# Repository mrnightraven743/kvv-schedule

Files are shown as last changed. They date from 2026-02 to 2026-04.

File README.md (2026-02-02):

# ESP32 Train Schedule Monitor (Deutsche Bahn Style)

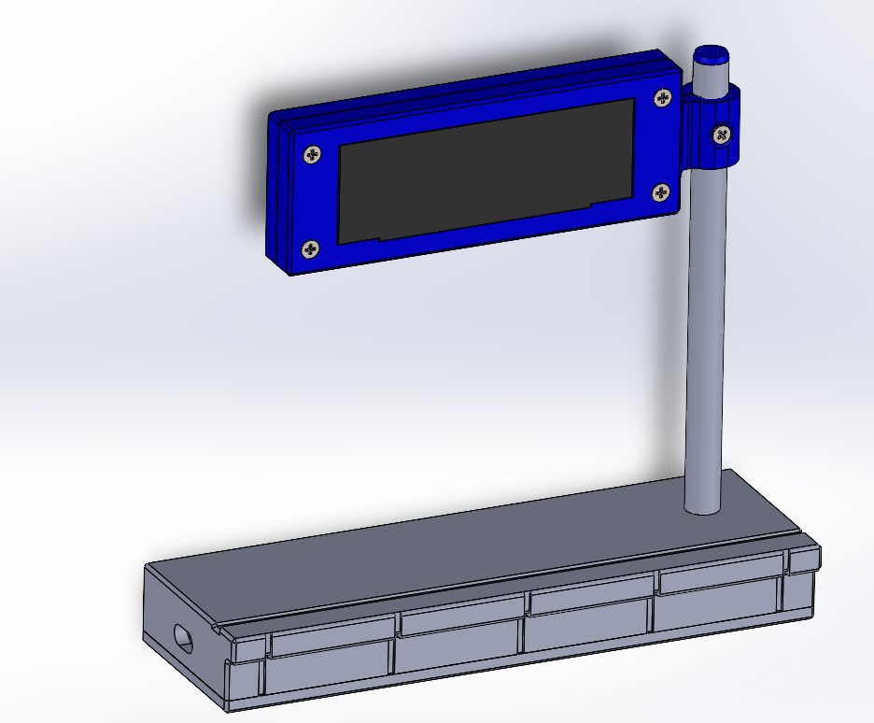
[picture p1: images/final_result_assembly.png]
Final Result


A desktop train schedule monitor stylized after the modern "DSA" (Dynamischer Schriftanzeiger) displays found on German railway platforms. It displays real-time departures for KVV (Karlsruher Verkehrsverbund) or Deutsche Bahn stations using an ESP32 and a high-resolution OLED display.

## ✨ Features

* **Hybrid Mode:** Fetches real-time data (API) when online. Falls back to a stored offline schedule if WiFi or the API is down.
* **Resilient Connectivity:** Auto-reconnects to WiFi. If the connection drops during the night, it updates as soon as the internet returns.
* **Automated Updates:**
    * **Backend:** GitHub Actions fetches the next 24h schedule every night (02:00 AM).
    * **Firmware:** The ESP32 downloads the new data file automatically at 03:00 AM (or upon reconnection).
* **Authentic Design:** Custom 3D-printed housing with an aluminum stand, modeled in SolidWorks.

## 📂 Repository Structure

* `firmware/`: MicroPython code for the ESP32 (Display driver, WiFi logic, Updater).
* `backend/`: Python script used by GitHub Actions to fetch data from KVV/EFA.
* `3d_models/`:
    * `stl/`: Ready-to-print files.
    * `step/`: CAD files for modification.
* `offline_data.py`: The daily generated schedule (updated automatically by the bot).

## 🛠 Hardware Required

1.  **MCU:** ESP32 DevKit V1 (30 pin).
2.  **Display:** 3.12" OLED SSD1322 (256x64 pixels, SPI interface).
3.  **Housing:** 3D printed parts (PLA/PETG) + Aluminum tube (10mm diameter).
4.  **Power:** USB Cable + 5V Adapter.

### Wiring (SPI)

| Display Pin | ESP32 Pin | Note |
| :--- | :--- | :--- |
| **VCC** | 3.3V | |
| **GND** | GND | |
| **SCK** (CLK) | GPIO 18 | |
| **MOSI** (DIN) | GPIO 23 | |
| **CS** | GPIO 5 | |
| **DC** | GPIO 17 | |
| **RST** | GPIO 16 | |

## 🚀 Installation Guide

### 1. GitHub Setup (Backend)
To enable automatic schedule updates, you need your own copy of this repository.

1.  **Fork** this repository.
2.  Go to `backend/kvv_processor.py` and change the `STOP_ID` to your desired station ID.
3.  Go to the **Actions** tab in your repository and enable workflows.
4.  (Optional) Run the "Update Schedule" workflow manually once to generate the first data file.

### 2. ESP32 Setup (Firmware)
1.  Flash your ESP32 with the latest **MicroPython** firmware.
2.  Open `firmware/main.py` and configure:
    * `WIFI_SSID` / `WIFI_PASS`: Your WiFi credentials.
    * `STOP_ID`: Your station ID (for real-time requests).
    * `LAT` / `LON`: Your coordinates (for local weather data).
3.  Open `firmware/schedule_updater.py` and update `GITHUB_RAW_URL` to point to **your** forked repository (`raw.githubusercontent.com/...`).
4.  Upload all files from the `firmware/` folder to the root directory of the ESP32.

## 🖨️ 3D Printing & Assembly

The design is modular and fully serviceable, using M3 bolts and nuts.

### Bill of Materials (BOM)
* **Bolts:**
    * M3 x 20mm (Required for the Base).
    * M3 x 25mm (Recommended for the Display Case, 20mm can also work, required for the Base at least 1).
    * Small screws (e.g., M2) for mounting the ESP32 (or use Superglue).
* **Nuts:** Standard M3 nuts.
* **Tube:** Aluminum tube, 10mm outer diameter.

### Printing Tips
* **Material:** PLA or PETG.
* **Adhesion:** The **Base** part is long and prone to warping. It is highly recommended to use **glue stick** or adhesive spray on the print bed to ensure it stays flat.
* **Nozzle:** Designed for a standard 0.4mm nozzle.

### Assembly Notes
1.  **The Screen Clips:**
    The mounting holes on the SSD1322 PCB are extremely close to the edge. Printing holes for them directly would result in fragile 1-layer walls. Instead, the screen is held in place by **special printed clips (clamps)** that are secured by the main case bolts. Do not try to put screws directly through the PCB holes.
2.  **The Tube (Drilling):**
    * **Display:** Assemble the front and back of the display case *first*. Then insert the tube and drill through the plastic and aluminum together. This ensures perfect alignment and prevents the drill from wobbling.
    * **Base:** Insert the tube into the base first, then drill the fixing hole.
3.  **The Tube (Fit):**
    The 10mm tube is designed for a **tight press-fit** into the Base. You may need to lightly hammer it in. This design feature prevents the tube from rotating even before the locking bolt is inserted.
4.  **ESP32 Mounting:**
    The ESP32 can be secured in the base using small screws (if your board has holes) or simply glued in place with a drop of superglue.

## 💡 Notes

**Keep-Alive Mechanism:**
GitHub disables Actions after 60 days of inactivity. To prevent this, I use a simple cron script on a local Raspberry Pi that pushes a small update to `keep_alive_log.txt` once a month. This ensures the daily schedule updates continue indefinitely without manual intervention.

## 📜 License
This project is open-source. Feel free to modify and build your own!

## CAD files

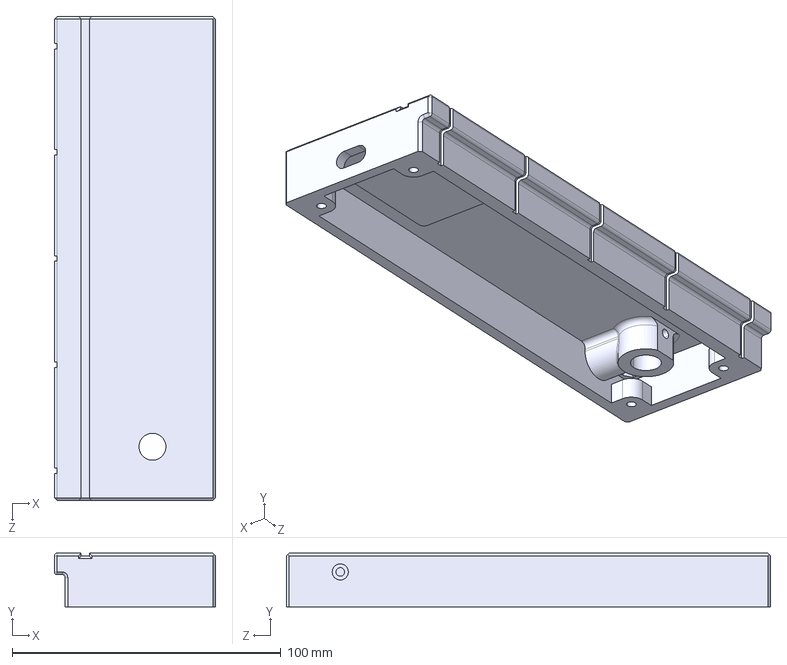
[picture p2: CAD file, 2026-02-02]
3d_models/step/base.STEP
60.0 x 20.0 x 180.0 mm

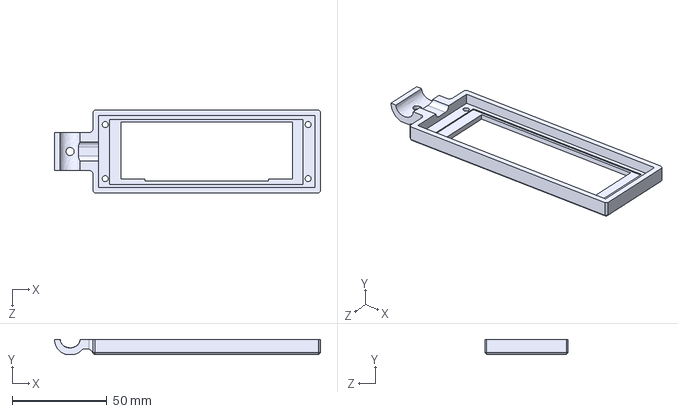
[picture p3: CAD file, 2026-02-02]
3d_models/step/display_housing_body.STEP
140.3 x 8.00 x 44.0 mm

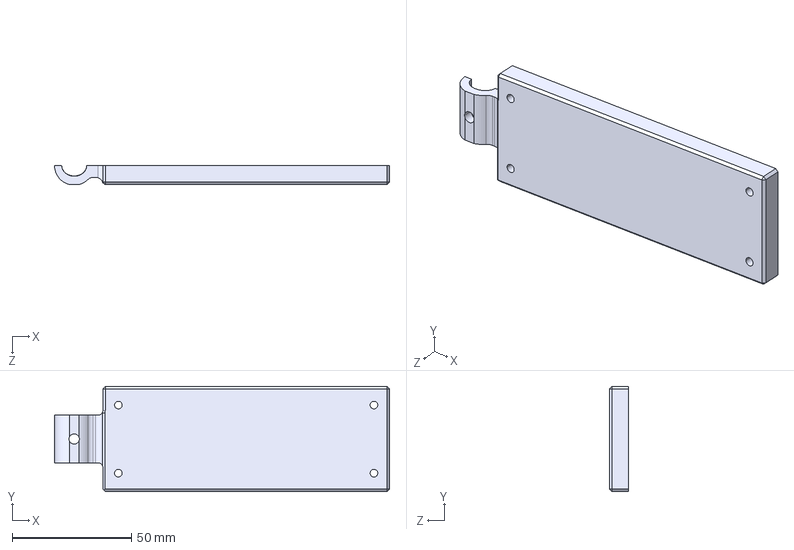
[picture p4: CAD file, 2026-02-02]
3d_models/step/display_housing_case.STEP
140.3 x 44.0 x 8.00 mm

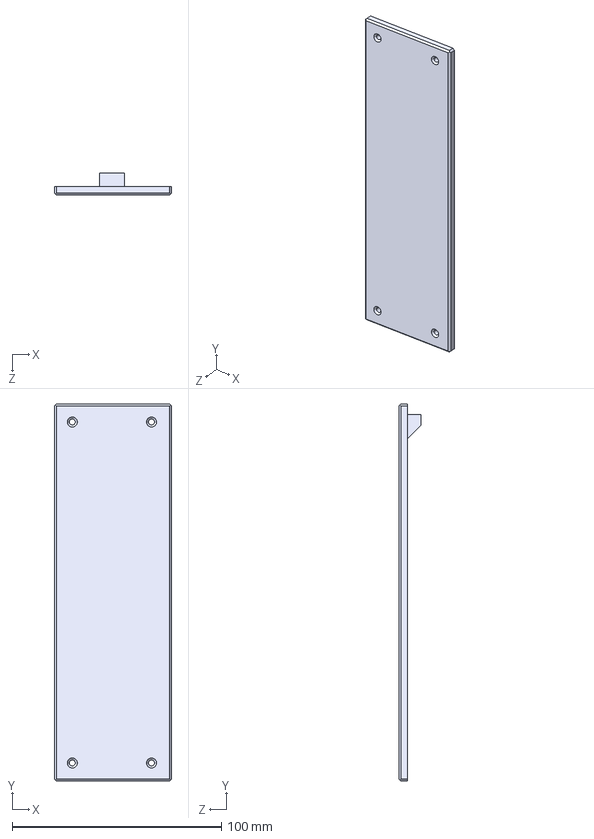
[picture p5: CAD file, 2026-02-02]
3d_models/step/base_lid.STEP
56.0 x 180.0 x 10.6 mm

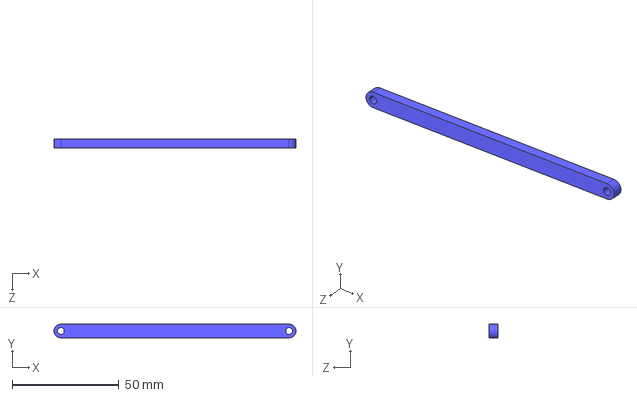
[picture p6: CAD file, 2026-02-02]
3d_models/step/display_holder.STEP
113.4 x 6.40 x 4.00 mm

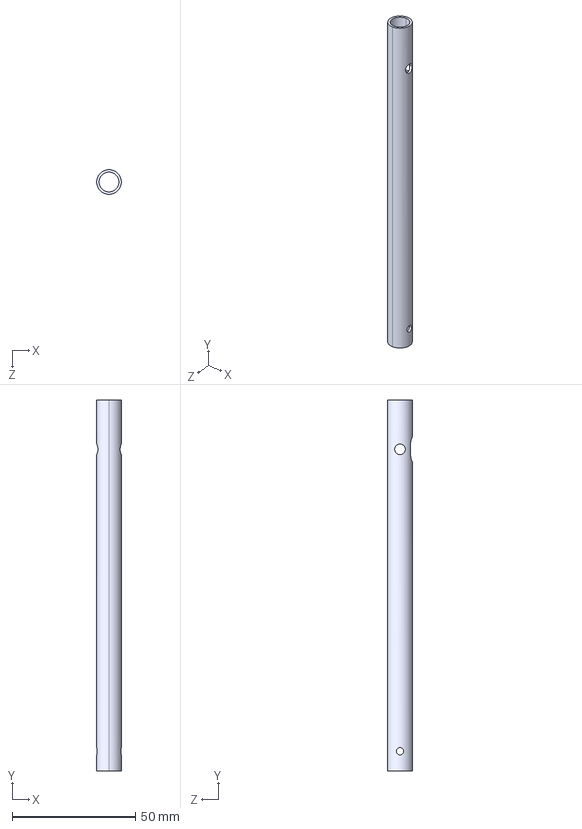
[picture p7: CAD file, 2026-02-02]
3d_models/step/tube_aluminium.STEP
10.0 x 150.4 x 10.0 mm

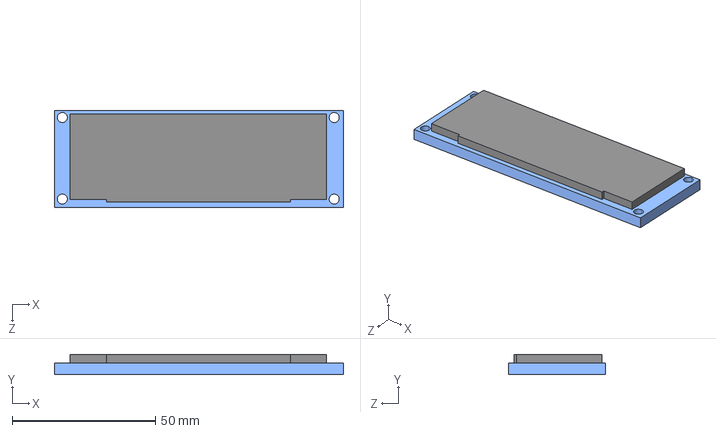
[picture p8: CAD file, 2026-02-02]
3d_models/step/monitor.STEP
101.0 x 7.00 x 34.0 mm

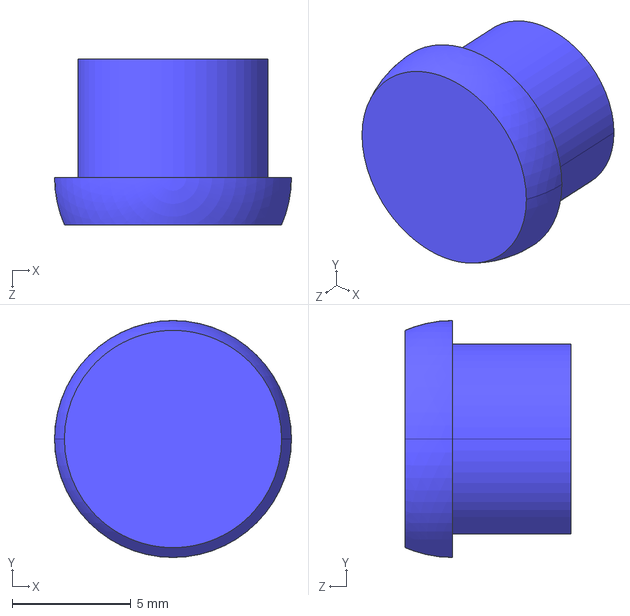
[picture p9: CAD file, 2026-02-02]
3d_models/step/pipe_top.STEP
10.00 x 10.0 x 7.00 mm

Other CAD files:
3d_models/stl/base.STL
3d_models/stl/base_lid.STL
3d_models/stl/display_holder.STL
3d_models/stl/display_housing_body.STL
3d_models/stl/display_housing_case.STL
3d_models/stl/pipe_top.STL

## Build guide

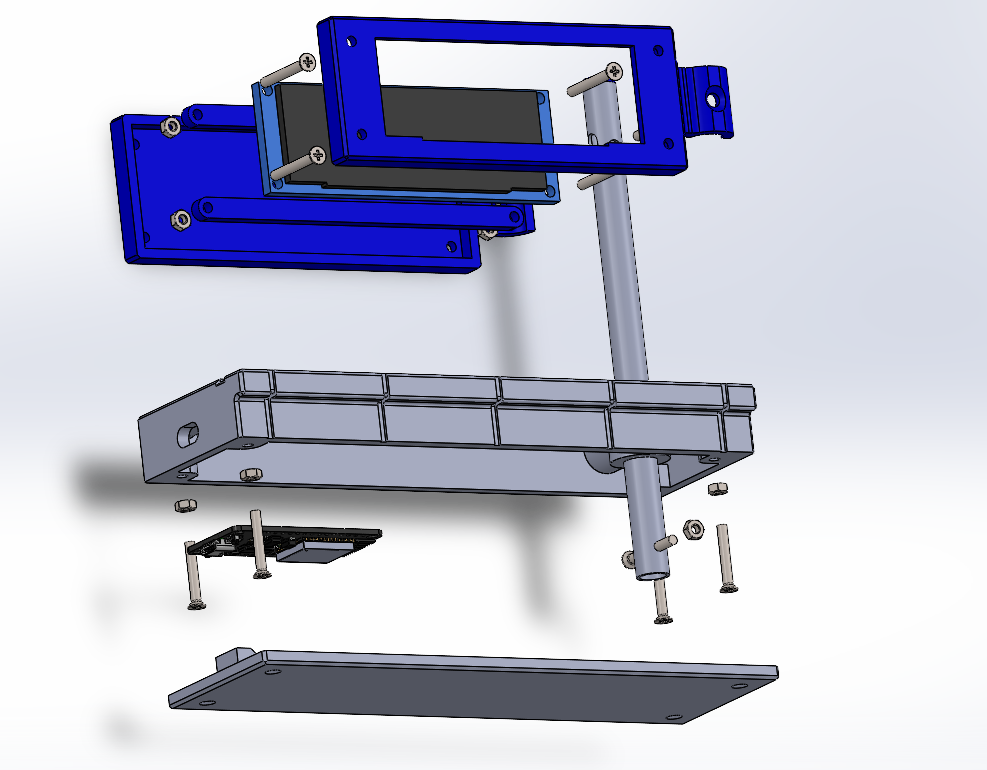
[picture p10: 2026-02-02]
images/final_result_assembly_exploded_view.png

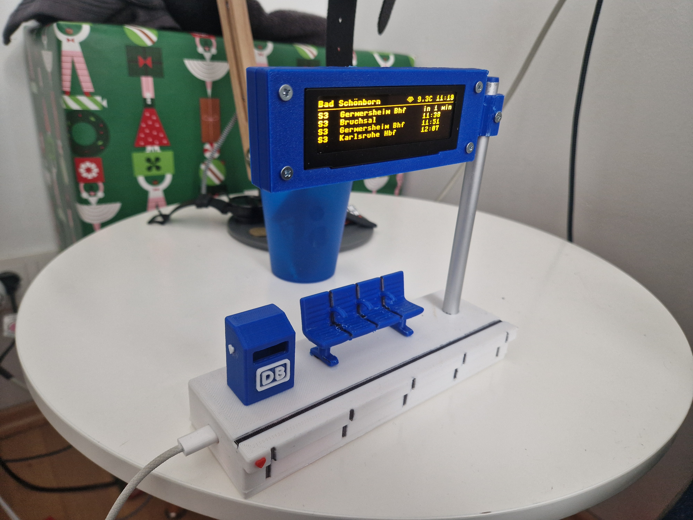
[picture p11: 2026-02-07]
images/3d_printed.jpg

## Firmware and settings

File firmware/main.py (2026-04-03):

import network
import time
import urequests
import json
import gc
import ntptime
import machine
import os
from machine import Pin, SPI, RTC
import ssd1322
import schedule_updater

# --- CONFIGURATION ---
WIFI_NETWORKS = [
    ("XXXX", "XXXX"),
    ("XXXX", "XXXX"),
    ("XXXX", "XXXX")
]

STOP_ID = "7001862" 
KVV_URL = f"http://www.kvv.de/tunnelEfaDirect.php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{STOP_ID}"
LAT = "49.2208"
LON = "8.6469"
WEATHER_URL = f"http://api.open-meteo.com/v1/forecast?latitude={LAT}&longitude={LON}&current_weather=true"

wifi_next_idx = 0

# --- DISPLAY CONFIGURATION ---
SPI_PORT = 2
SCK_PIN = 18
MOSI_PIN = 23
CS_PIN = 5
DC_PIN = 17
RST_PIN = 16

# Display reset sequence
rst = Pin(RST_PIN, Pin.OUT)
rst.value(1)
time.sleep(0.1)
rst.value(0)
time.sleep(0.2)
rst.value(1)
time.sleep(0.5)

spi = SPI(SPI_PORT, baudrate=10000000, sck=Pin(SCK_PIN), mosi=Pin(MOSI_PIN))
display = ssd1322.SSD1322(256, 64, spi, Pin(RST_PIN), Pin(CS_PIN), Pin(DC_PIN))

# WiFi initialization
wlan = network.WLAN(network.STA_IF)
try:
    wlan.active(True)
    wlan.config(pm=0xa11140)
except:
    pass

rtc = RTC()
last_weather = "" 
update_done_today = False 

# Import offline schedule data safely
try:
    import offline_data
except ImportError:
    offline_data = None 

# Text replacement dictionary to fit names on screen
REPLACEMENTS = {
    "Bahnhof": "Bhf", 
    "Straße": "Str.", 
    "Platz": "Pl.", 
    "Kaiserslautern, Hauptbahnhof": "Kaiserslautern", 
    "Kaiserslautern, Hbf": "Kaiserslautern", 
    "Kaiserslautern Hbf": "Kaiserslautern", 
    "Homburg (Saar) Hbf": "Homburg Hbf", 
    "Homburg (Saar)": "Homburg",
    "Hauptbahnhof": "Hbf",
    ", ": " ",
    
    "Вікторія": "Sonechko",
    "Наталя": "Mutter"
}

# Bitmap for WiFi icon
WIFI_BITMAP = ["   XXXXXXX   ", "  X       X  ", " X  XXXXX  X ", "X  X     X  X", "  X  XXX  X  ", "    X   X    ", "      X      "]

def shorten_text(text):
    """Abbreviates station names using the REPLACEMENTS dictionary."""
    for full, short in REPLACEMENTS.items():
        text = text.replace(full, short)
    
    if len(text) > 19:
        text = text[:19] + "."
    return text

def draw_umlaut_o(x, y):
    """Draws custom umlaut dots over 'o'."""
    display.pixel(x + 2, y - 1, 15)
    display.pixel(x + 5, y - 1, 15)
    
def draw_umlaut_a(x, y):
    """Draws custom umlaut dots over 'a'."""
    display.pixel(x + 2, y - 1, 15)
    display.pixel(x + 5, y - 1, 15)

def draw_wifi_icon(x, y, connected):
    """Draws WiFi icon if connected, or a cross if disconnected."""
    if connected:
        for r, s in enumerate(WIFI_BITMAP):
            for c, char in enumerate(s):
                if char == 'X':
                    display.pixel(x + c, y + r, 15)
    else:
        # Static cross
        display.line(x, y, x+9, y+8, 15)
        display.line(x+9, y, x, y+8, 15)

def wifi_reset():
    """Hardware reset for the WiFi interface."""
    print("WiFi Interface Reset...")
    try:
        wlan.active(False)
        time.sleep(0.5)
        wlan.active(True)
        time.sleep(0.5)
    except:
        pass

def safe_connect(silent=False):
    """
    Connects to WiFi. 
    silent=False: Blocking loop with display updates (used on startup).
    silent=True: Background mode, tries one network and exits.
    """
    global wifi_next_idx
    
    # Return if already connected
    if wlan.isconnected():
        return True

    # MODE 1: Startup (Blocking with display)
    if not silent:
        print("Starting WiFi Loop (Blocking)...")
        while True:
            for ssid, password in WIFI_NETWORKS:
                print(f"Trying: {ssid}")
                
                # Prepare screen
                display_ssid = shorten_text(ssid)
                if len(display_ssid) > 19: display_ssid = display_ssid[:19]

                display.fill(0)
                display.text("WiFi Connect...", 0, 2, 15)
                display.hline(0, 12, 256, 6)
                display.text(f"Try: {display_ssid}", 0, 30, 15)
                display.show()

                try:
                    # Disconnect before new attempt
                    wlan.disconnect() 
                    time.sleep(0.5)  
                    wlan.connect(ssid, password)
                except OSError:
                    continue
                
                # Wait up to 8 seconds for connection
                for _ in range(8):
                    if wlan.isconnected():
                        display.text("OK!", 200, 30, 15); display.show()
                        time.sleep(1)
                        return True
                    time.sleep(1)
            
            # If all networks fail, reset WiFi
            display.fill(0)
            display.text("No WiFi found", 0, 20, 15)
            display.text("Resetting...", 0, 35, 15)
            display.show()
            wifi_reset()

    # MODE 2: Background (Silent)
    else:
        # Try the next network in the list
        if wifi_next_idx >= len(WIFI_NETWORKS):
            wifi_next_idx = 0
            
        ssid, password = WIFI_NETWORKS[wifi_next_idx]
        print(f"Background attempt: {ssid}")
        
        try:
            wlan.disconnect()
            time.sleep(0.1)
            wlan.connect(ssid, password)
        except OSError:
            pass
            
        # Update index for next time
        wifi_next_idx += 1
        return False
        
def sync_time():
    """Syncs local time via NTP."""
    try:
        ntptime.settime()
        return True
    except:
        return False

# --- ROBUST TIME FUNCTION (Logic based, No mktime) ---
def get_cet_time():
    """
    Returns local time (tuple) for Germany (CET/CEST).
    Uses logical date comparison instead of mktime to avoid OS dependencies.
    """
    utc = time.gmtime()
    year, month, day, hour = utc[0], utc[1], utc[2], utc[3]

    # Gauss algorithm for last Sunday
    march_last_sunday = 31 - (int(5 * year / 4 + 4) % 7)
    oct_last_sunday = 31 - (int(5 * year / 4 + 1) % 7)

    # Logical DST determination
    is_dst = (
        (month > 3 and month < 10) or
        (month == 3 and (day > march_last_sunday or (day == march_last_sunday and hour >= 1))) or
        (month == 10 and (day < oct_last_sunday or (day == oct_last_sunday and hour < 1)))
    )

    offset = 2 if is_dst else 1
    
    # Add offset to current UTC timestamp and convert back
    return time.gmtime(time.time() + offset * 3600)

def get_static_schedule(current_h, current_m):
    """Generates departures from offline data if API is unreachable."""
    if offline_data is None or not hasattr(offline_data, 'SCHEDULE'):
        return []
        
    departures = []
    for h_offset in [0, 1]:
        check_h = (current_h + h_offset) % 24
        trains = offline_data.SCHEDULE.get(check_h, [])
        for minute, line, dest in trains:
            train_time_abs = check_h * 60 + minute
            now_time_abs = current_h * 60 + current_m
            
            # Handle midnight rollover
            if check_h < current_h:
                train_time_abs += 24 * 60
            
            diff = train_time_abs - now_time_abs
            if 0 <= diff <= 90:
                short_dest = shorten_text(dest)
                departures.append({
                    'line': line,
                    'direction': short_dest,
                    'time': "{:02d}:{:02d}".format(check_h, minute),
                    'countdown': diff,
                    'is_real': False
                })
    departures.sort(key=lambda x: x['countdown'])
    return departures

def get_live_schedule():
    """Fetches weather and transport data from APIs."""
    global last_weather
    gc.collect() 
    
    # --- 1. Weather Update ---
    try:
        res = urequests.get(WEATHER_URL)
        if res.status_code == 200:
            js = json.loads(res.text)
            temp = js.get('current_weather', {}).get('temperature')
            last_weather = f"{temp}C"
        if res: res.close()
    except:
        pass 
    gc.collect()

    # --- 2. Transport Update ---
    for attempt in range(2):
        res = None
        try:
            res = urequests.get(KVV_URL)
            if res.status_code == 200:
                data = json.loads(res.text)
                res.close()
                res = None
                gc.collect()
                
                parsed = []
                dep_list = data.get('departureList', [])
                del data
                
                for dep in dep_list:
                    line = dep.get('servingLine', {}).get('symbol', '?')
                    direction = dep.get('servingLine', {}).get('direction', 'Unknown')
                    
                    if '>' in direction:
                        direction = direction.split('>')[0].strip()
                    
                    # Check if trip is cancelled (via status or text)
                    status = dep.get('realtimeTripStatus', '').upper()
                    is_cancelled = ('CANCEL' in status) or ('ENTF' in direction.upper())
                    
                    real_dt = dep.get('realDateTime', dep.get('dateTime', {}))
                    rh = int(real_dt.get('hour', 0))
                    rm = int(real_dt.get('minute', 0))
                    
                    cd_str = dep.get('countdown', '0')
                    try: cd = int(cd_str)
                    except: cd = 0
                    
                    parsed.append({
                        'line': line,
                        'direction': shorten_text(direction),
                        'time': "{:02d}:{:02d}".format(rh, rm),
                        'countdown': cd,
                        'is_real': True,
                        'cancelled': is_cancelled
                    })
                del dep_list
                gc.collect()
                return parsed
            else:
                if res: res.close()
        except OSError as e:
            error_code = e.args[0] if e.args else 0
            if error_code in [16, 118, -202]:
                wifi_reset()
            else:
                time.sleep(1)
        except Exception:
            time.sleep(1)
        finally:
            if res:
                try: res.close()
                except: pass
            gc.collect()
    return None

def update_display(deps, time_str, online):
    """Draws the main interface and departure list on the screen."""
    display.fill(0)
    display.text("Bad Schonborn", 0, 2, 15)
    draw_umlaut_o(56, 2) 
    
    # Shifted time
    time_x = 190
    display.text(time_str, time_x + 26, 2, 15)
    
    cursor_x = 216 
    # Weather only if online
    if online and last_weather:
        w_len = len(last_weather) * 8
        cursor_x = 216 - w_len - 8
        display.text(last_weather, cursor_x, 2, 10)
    
    draw_wifi_icon(cursor_x - 21, 2, online)
    display.hline(0, 12, 256, 6)

    y = 16 
    if not deps:
        display.text("Keine Daten...", 0, 20, 15)
        if not online:
            display.text("Warte auf WiFi...", 0, 30, 10)
    else:
        if not deps[0]['is_real']:
             # Centered OFFLINE PLAN warning
             display.text("* OFFLINE PLAN *", 64, 56, 10)
        
        cnt = 0
        seen = {}
        for d in deps:
            if cnt >= 4: break
            dst = d['direction']
            # Limit duplicates for the same destination
            if seen.get(dst, 0) >= 2: continue
            seen[dst] = seen.get(dst, 0) + 1
            
            if d.get('cancelled', False):
                t = "entfallt"
            else:
                t = "sofort" if d['countdown'] == 0 else (f"in {d['countdown']} min" if d['countdown']<=9 else d['time'])
            
            display.text(d['line'], 0, y, 15)
            display.text(dst, 35, y, 10)
            display.text(t, time_x, y, 15)
            
            # Draw umlaut 'a' if train is cancelled
            if d.get('cancelled', False):
                draw_umlaut_a(time_x + 32, y)
            
            y += 10
            cnt += 1
    display.show()

def show_status(msg):
    """Displays system status messages."""
    display.fill(0)
    display.text("System Info", 0, 2, 15)
    display.hline(0, 12, 256, 6)
    display.text(msg, 0, 30, 15)
    display.show()

def save_update_date():
    """Save current date (YYYYMMDD) to file to track offline data updates."""
    try:
        t = get_cet_time()
        # Format: YYYYMMDD (e.g. 20231025)
        date_str = "{}{:02d}{:02d}".format(t[0], t[1], t[2])
        with open('last_upd.txt', 'w') as f:
            f.write(date_str)
    except: pass

def check_if_updated_today():
    """Check if schedule update was already performed today."""
    try:
        t = get_cet_time()
        current_date_str = "{}{:02d}{:02d}".format(t[0], t[1], t[2])
        
        with open('last_upd.txt', 'r') as f:
            saved_date_str = f.read().strip()
            if saved_date_str == current_date_str:
                return True
    except: pass
    return False

def main():
    global update_done_today
    
    display.fill(0); display.text("System Start...", 0, 30, 15); display.show()
    print("Start")
    time.sleep(1)

    # --- 1. INITIAL CONNECTION ---
    if not safe_connect():
        while not wlan.isconnected():
            show_status("Waiting for WiFi...")
            wifi_reset()
            time.sleep(5)
    
    show_status("Syncing Time...")
    sync_time()
    
    # Check if schedule was already updated today
    if check_if_updated_today():
        print("Already updated today.")
        update_done_today = True

    # --- 2. FILE CHECK ---
    try:
        os.stat('offline_data.py')
    except OSError:
        show_status("Downloading Data...")
        if schedule_updater.update_from_github():
            save_update_date()
            # Success -> Countdown 10 sec before reboot
            for i in range(10, 0, -1):
                show_status(f"Success! Reboot {i}s")
                time.sleep(1)
            machine.reset()
        else:
            show_status("Download Failed!")
            time.sleep(2)

    last_update = 0
    reconnect_timer = 0
    last_retry_time = 0 
    
    # --- 3. MAIN LOOP ---
    while True:
        now = time.ticks_ms()
        
        # Get correct local time (CET/CEST)
        t = get_cet_time()
        h = t[3]
        m = t[4]
        time_str = "{:02d}:{:02d}".format(h, m)
        
        online = wlan.isconnected()
        
        # Reset update flag at 2 AM
        if h == 2: update_done_today = False
        
        # --- UPDATE LOGIC ---
        if h >= 3 and online and not update_done_today:
            # Pause between attempts (10 minutes)
            if time.ticks_diff(now, last_retry_time) > 600000 or last_retry_time == 0:
                show_status("Updating Schedule...")
                if schedule_updater.update_from_github():
                    save_update_date()
                    for i in range(10, 0, -1):
                        show_status(f"Updated! Reboot {i}s")
                        time.sleep(1)
                    machine.reset()
                else:
                    last_retry_time = now
                    show_status("Update Fail. Retry later.")
                    time.sleep(2)

        # --- WIFI MANAGEMENT ---
        if not online:
            # Reconnect every 15 seconds if offline
            if time.ticks_diff(now, reconnect_timer) > 15000:
                reconnect_timer = now
                safe_connect(silent=True) 
        else:
            # Sync time once an hour
            if t[4] == 0 and t[5] < 5:
                sync_time()

        # --- DISPLAY UPDATE ---
        if time.ticks_diff(now, last_update) > 30000:
            print("Upd...", end=" ")
            gc.collect()
            
            deps = None
            if online:
                deps = get_live_schedule()
            
            if deps:
                update_display(deps, time_str, True)
                print("Online")
            else:
                print("Offline")
                deps = get_static_schedule(h, m)
                update_display(deps, time_str, online)
            
            last_update = now
            
        time.sleep(0.5)

if __name__ == '__main__':
    main()

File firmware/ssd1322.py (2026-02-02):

# save as lib/ssd1322.py
import framebuf
from micropython import const

_SET_COL_ADDR = const(0x15)
_SET_ROW_ADDR = const(0x75)
_WRITE_RAM = const(0x5C)
_READ_RAM = const(0x5D)
_SET_REMAP = const(0xA0)
_SET_START_LINE = const(0xA1)
_SET_OFFSET = const(0xA2)
_ENTIRE_ON_NORMAL = const(0xA4)
_ENTIRE_ON_ALL = const(0xA5)
_ENTIRE_OFF = const(0xA6)
_INVERSE_OFF = const(0xA6)
_INVERSE_ON = const(0xA7)
_SET_MUX_RATIO = const(0xCA)
_SET_COMMAND_LOCK = const(0xFD)
_SET_CONTRAST_CURRENT = const(0xC1)
_SET_MASTER_CURRENT = const(0xC7)
_SET_PRECHARGE_VOLTAGE = const(0xBB)
_SET_VCOMH_VOLTAGE = const(0xBE)
_EXIT_SLEEP = const(0xAF)
_SET_SLEEP = const(0xAE)
_SET_PHASE_LENGTH = const(0xB1)
_SET_CLOCK_DIV = const(0xB3)
_SET_PRECHARGE_PERIOD = const(0xB6)
_SET_SECOND_PRECHARGE_PERIOD = const(0xB6)

class SSD1322(framebuf.FrameBuffer):
    def __init__(self, width, height, spi, res, cs, dc):
        self.width = width
        self.height = height
        self.spi = spi
        self.res = res
        self.cs = cs
        self.dc = dc
        self.buffer = bytearray(self.width * self.height // 2)
        # GS4_HMSB means 4-bit grayscale (16 shades of gray)
        super().__init__(self.buffer, self.width, self.height, framebuf.GS4_HMSB)
        self.res.init(self.res.OUT, value=1)
        self.cs.init(self.cs.OUT, value=1)
        self.dc.init(self.dc.OUT, value=0)
        self.init_display()

    def write_cmd(self, cmd):
        self.cs(0)
        self.dc(0)
        self.spi.write(bytearray([cmd]))
        self.cs(1)

    def write_data(self, data):
        self.cs(0)
        self.dc(1)
        self.spi.write(bytearray([data]))
        self.cs(1)

    def init_display(self):
        self.res(1)
        import time
        time.sleep_ms(1)
        self.res(0)
        time.sleep_ms(10)
        self.res(1)
        
        self.write_cmd(_SET_COMMAND_LOCK)
        self.write_data(0x12)  # Unlock
        self.write_cmd(_SET_SLEEP) # Display OFF
        
        self.write_cmd(_SET_CLOCK_DIV)
        self.write_data(0x91)
        self.write_cmd(_SET_MUX_RATIO)
        self.write_data(0x3F) # 1/64 duty
        self.write_cmd(_SET_OFFSET)
        self.write_data(0x00)
        self.write_cmd(_SET_START_LINE)
        self.write_data(0x00)
        
        self.write_cmd(_SET_REMAP)
        self.write_data(0x14) # Horizontal address increment, Disable Column Address Re-map, Enable Nibble Re-map
        self.write_data(0x11) # Dual COM line mode
        
        self.write_cmd(_SET_CONTRAST_CURRENT) # Яркость
        self.write_data(0x7F) # Max 0xFF
        
        self.write_cmd(_SET_MASTER_CURRENT)
        self.write_data(0x0F) # Max
        
        self.write_cmd(_EXIT_SLEEP) # Display ON

    def show(self):
        self.write_cmd(_SET_COL_ADDR)
        self.write_data(0x1C) # Start column
        self.write_data(0x5B) # End column
        self.write_cmd(_SET_ROW_ADDR)
        self.write_data(0x00)
        self.write_data(0x3F)
        self.write_cmd(_WRITE_RAM)
        self.cs(0)
        self.dc(1)
        self.spi.write(self.buffer)
        self.cs(1)

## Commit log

2026-01-29 Add KVV processor for fetching and saving schedules
    This script fetches and processes KVV departure data for the next day, filtering for S-Bahn lines and generating a schedule saved to offline_data.py.
2026-02-02 Update README with project details and setup instructions
    Added detailed project description, features, repository structure, hardware requirements, installation guide, 3D printing tips, and notes.
